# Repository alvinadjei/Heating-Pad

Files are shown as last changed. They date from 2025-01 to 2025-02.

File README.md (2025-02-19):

# Electric Heating Pad

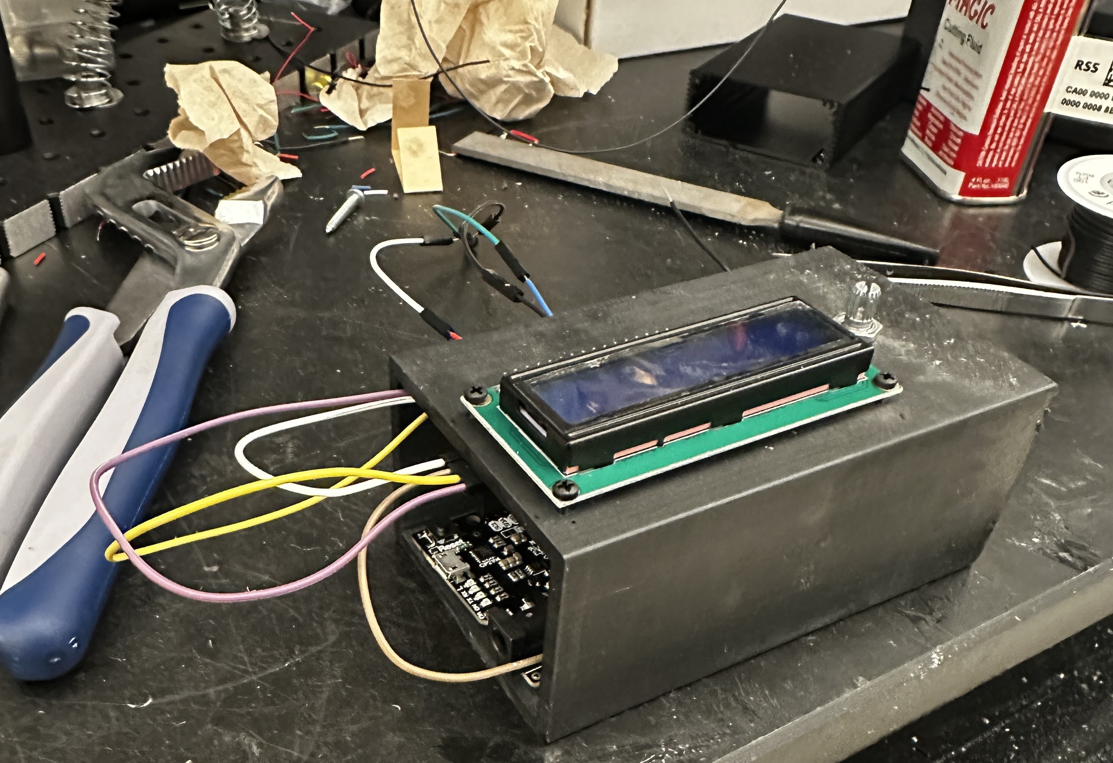
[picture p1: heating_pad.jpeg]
Heating pad circuitry


<p>
  This repository contains code and circuit diagram for building a feedback-controlled heating pad to regulate a mouse's body temperature while 
it is under anesthesia. The device monitors the mouse's body temperature, and supplies heat accordingly to maintain a temperature within a comfortable range.
</p>

Author(s): Alvin Adjei, University of California San Francisco

## Requirements

- 1 $\times$
  <a href="https://store.arduino.cc/products/arduino-uno-rev3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">
    Arduino Uno
  </a>
  or similar microcontroller (we used an
  <a href="https://www.adafruit.com/product/2488">
    Adafruit Metro Board
  </a>)
- 1 $\times$ potentiometer
- 1 $\times$
  <a href="https://www.adafruit.com/product/165">
    TMP36 temperature sensor
  </a>
- 1 $\times$
  <a href="https://www.adafruit.com/product/355">
    N-channel mosfet
  </a>
- 1 $\times$
  <a href="https://learn.adafruit.com/make-it-hot-or-cold/make-it-hot">
    electric heating pad
  </a>
- 1 $\times$
  <a href="https://www.sunfounder.com/collections/lcd-display/products/i2c-lcd1602-module">
    SunFounder LCD1602 Display Module
  </a>

## Assembly

<figure>
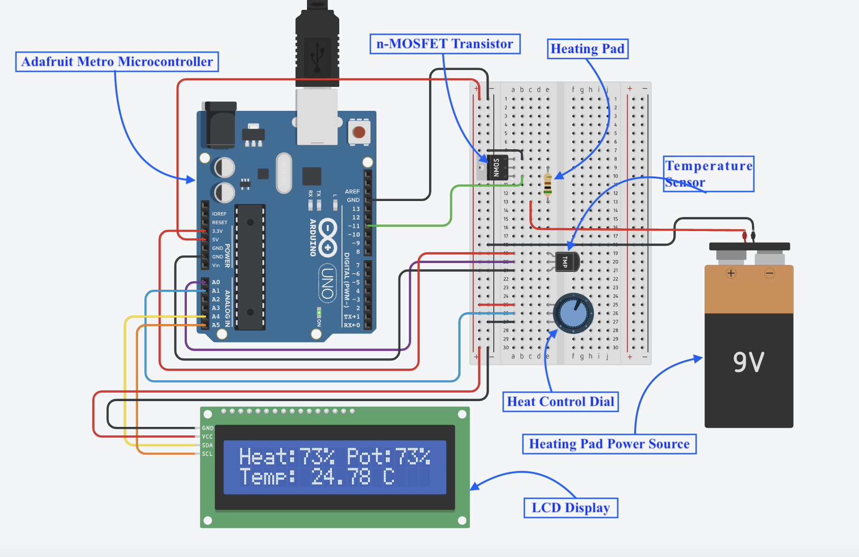
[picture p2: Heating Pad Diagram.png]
Circuit Diagram
  
  <figcaption>
    Circuit diagram. The resistor on the breadboard represents the heating pad component.
    View circuit diagram in <a href="https://www.tinkercad.com/things/876OW5vUT7l-mouse-heating-pad-potentiometer">Tinkercad</a>.
  </figcaption>
</figure>
<br><br>
<figure>
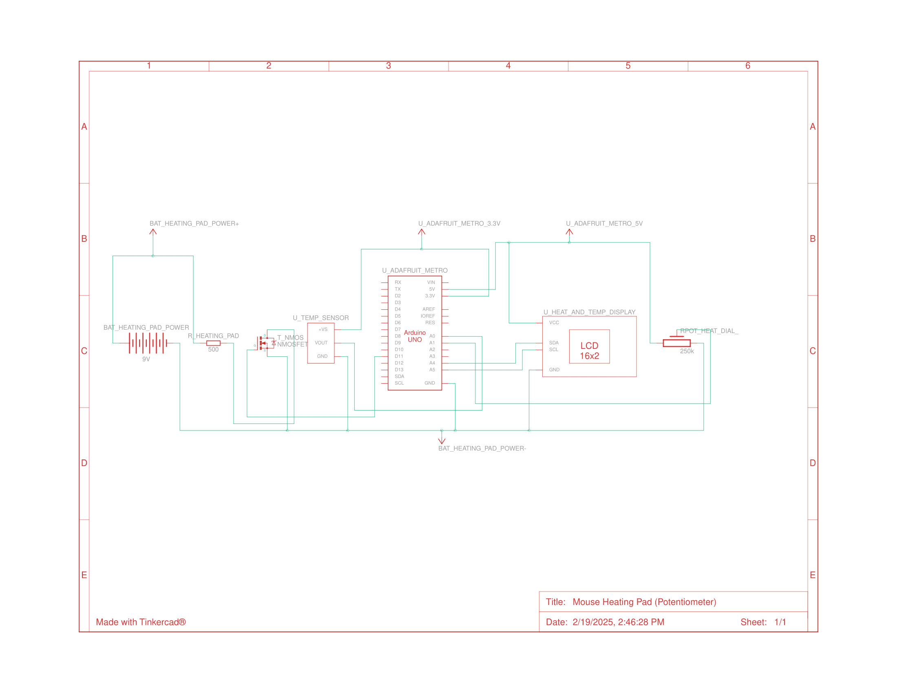
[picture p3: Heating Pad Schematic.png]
Circuit Schematic
  
  <figcaption>
    Circuit schematic.
  </figcaption>
</figure>

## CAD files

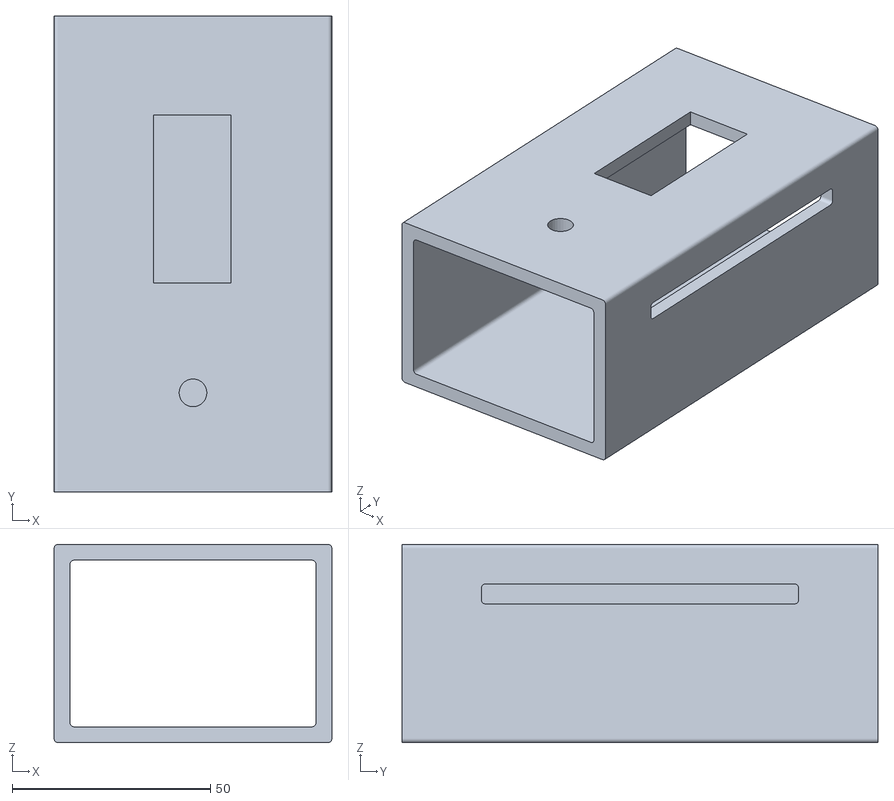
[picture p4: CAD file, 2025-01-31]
electronics_box/heating_pad_electronics_box.stl
70.0 x 120.0 x 50.0

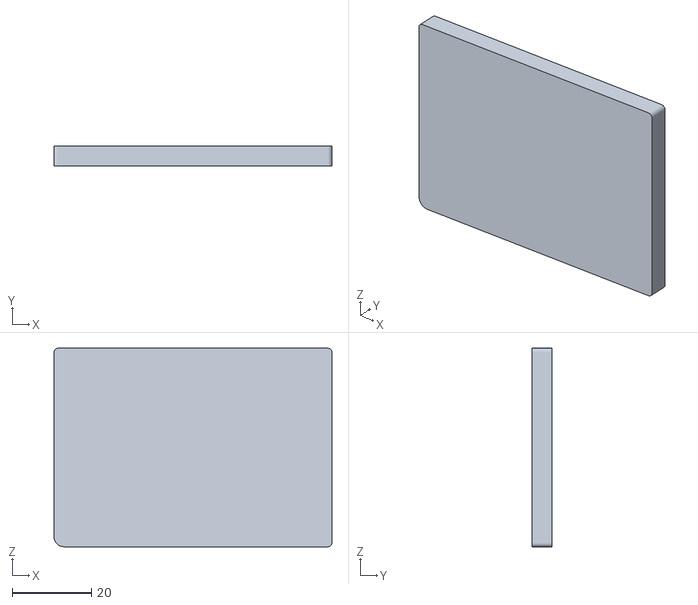
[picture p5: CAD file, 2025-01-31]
electronics_box/heating_pad_electronics_box_cover.stl
70.0 x 5.00 x 50.0

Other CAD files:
electronics_box/heating_pad_electronics_box.f3d
electronics_box/heating_pad_electronics_box_cover.f3d

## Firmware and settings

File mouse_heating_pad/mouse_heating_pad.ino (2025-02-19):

#include <Wire.h> 
#include <LiquidCrystal_I2C.h>

LiquidCrystal_I2C lcd(0x27,16,2);  // set the LCD address to 0x27 for a 16 chars and 2 line display

const int heatPin = 11; // pin that controls the heating pad
const int tempPin = A0; // pin that reads temp sensor value
const int potPin = A1; // pin that reads potentiometer value
const float sensorVoltage = 5.0; // mV; if temp sensor is plugged into the 5.5V pin
// const float sensorVoltage = 3.3; // mV; if temp sensor is plugged into the 3.3V pin

// Bounds between which to keep mouse body temp (36.6 +/- 0.5)
const float lowerBound = 36.1;
const float upperBound = 37.1;

int reading; // temp sensor --> ADC reading (0-1023)
float voltage; // convert tempReading to millivolts
float degreesC; // convert mv to degrees C
float degreesF; // convert mv to degrees F

int pot; // potentiometer pin reading

int heat; // energy sent to heating pad

void setup() {
  heat = 155; // initial signal to heating pad
  
  lcd.init();                      // initialize the lcd 
  lcd.backlight();

  Serial.begin(9600);
}

void loop() {
  reading = analogRead(tempPin); // read analog pin
  voltage = (reading / 1023.0) * sensorVoltage * 1000; // convert to millivolts
  degreesC = (voltage - 500) / 10; // convert to degrees C
  degreesF = (degreesC * 9/5) + 32; // convert to degrees F
  
  // if the pad is too cold
  if (degreesC < lowerBound) {
    heat += 10; // increase heat slightly
  }

  // Don't increase heat past 255
  if (heat > 255) {
    heat = 255;
  }
  
  // if the pad is too hot
  else if (degreesC > upperBound) {
    heat -= 10; //
  }

  // Don't decrease heat past 0
  if (heat < 0) {
    heat = 0;
  }
  
  // Failsafe:
  if ((degreesC < 20 && heat < 155) || (degreesC > 40.0 && heat > 155)) { // Mouse is way too cold or hot
    heat = 155;
  }
  
  // Normalize 10-bit potentiometer reading to be between 0 and 1
  pot = analogRead(potPin);
  float pot_norm = pot / 1023.0;

  // Control actualHeat value with potentiometer (failsafe)
  int actualHeat = (int)(heat * pot_norm);

  analogWrite(heatPin, actualHeat); // Send appropriate heat level to heating pad

  // Convert actualHeat (0-255) to percentage
  int heatDisplay = map(actualHeat, 0, 255, 0, 100);

  // Print to LCD display
  lcd.setCursor(0, 0);
  lcd.print("Heat:");
  lcd.print(heatDisplay);
  lcd.print("% ");
  lcd.print("Pot:");
  lcd.print((int)(pot_norm * 100));
  lcd.print("%");
  lcd.setCursor(0, 1);
  lcd.print("Temp: ");
  lcd.print(degreesC);
  lcd.print(" C");

  Serial.print("Heat: ");
  Serial.print(heatDisplay);
  Serial.println("%");

  Serial.print("ADC Reading: ");
  Serial.print(reading);
  Serial.print("; Millivolts: ");
  Serial.print(voltage);
  Serial.print("mV; Degrees C: ");
  Serial.print(degreesC);
  Serial.print("; Degrees F: ");
  Serial.print(degreesF);
  Serial.print("\n");

  delay(1000);
  lcd.clear();
}

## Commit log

2025-01-31 Rearranged files
    [heating_pad_electronics_box.f3d, heating_pad_electronics_box.stl, heating_pad_electronics_box_cover.f3d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]
2025-02-03 Create README.md
    Add intro, circuit diagram, and requirements
2025-02-03 Update README.md
    Added circuit diagram caption
2025-02-03 Heating Pad Box image added
2025-02-03 Update README.md
    Added circuit image
2025-02-04 Update README.md
    Fixed Arduino typo
2025-02-19 Updated LCD display
    LCD display now shows percentage of max heat being displayed, as well as percentage setting on potentiometer
2025-02-19 Update README.md
    Add schematic
2025-02-19 Add schematic image
2025-02-19 Update README.md
    Add caption to schematic image
